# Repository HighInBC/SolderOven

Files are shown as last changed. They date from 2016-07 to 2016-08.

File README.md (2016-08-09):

# SolderOven
A control board to turn a toaster oven and a relay into a solder oven

While this is a public project I am not planning on documenting it until it is somewhat ready.

Consider this to be at the pre-alpha development stage. Things **DO NOT WORK** yet.

##Purpose

The purpose of this board is to act as a solder oven control board.
In addition to providing a user interface it will use a relay to control a toaster oven to provide the functionality of a solder oven.

##Features

Not all of these features are functional yet.

###Microcontroller

An ATMEGA328P-AU sits at the heart of the device controlling all of the other components.

###I2C display

Using an I2C port for an external display will allow a wide variety of choices that can be implemented in firmware

###Rotary encoder

A rotary encoder with a push button will be the primary source of user interaction.

###RGB LED

A ws2812b LED will be able to switch to any color or brightness to act as an indicator.

###Buzzer

A small piezo buzzer is used to make audio signals to the user

###Reset button

To reset the unit

###Serial port

The serial port can be used to reprogram the device.
It features an auto reset circuit on the DTR line to mimic the behaviour of an arduino nano but with an external FTDI bpard.

When not being used for programming the port can be used for peripherals such as a wifi bridge or sd card logger.

###Thermocouple sensor

A MAX6675 is used to read and digitize the signal from a type-k thermocouple. Two female 4mm banana plug sockets are on the board for easy connection. This is used to monitor the temperature of the oven.

###External temperature sensor

A port to attach one or more DS18B20 temperature sensors is available. This is used to monitor the temperature of the relay and its housing, further sensors can be added as it is a 1-wire protocol. Has a built in 4.7K pull-up resistor on the data pin for the 1-wire interface.

###Relay output

A port to attach the logic side of a relay to. It is expected that the relay takes a 5V logic level signal and does its own current limiting under 40mA. If your relay needs more than that then you need to add a suitable transistor.

##Associated datasheets

* [ATMEGA382P-AU](http://www.atmel.com/images/Atmel-8271-8-bit-AVR-Microcontroller-ATmega48A-48PA-88A-88PA-168A-168PA-328-328P_datasheet_Complete.pdf)
* [WS2812B](https://cdn-shop.adafruit.com/datasheets/WS2812B.pdf)
* [MAX6675](https://datasheets.maximintegrated.com/en/ds/MAX6675.pdf)
* [DS18B20](https://datasheets.maximintegrated.com/en/ds/DS18B20.pdf)
* [S8050](http://www.gangyi.com.cn/UploadFiles/2007828165749876.pdf)

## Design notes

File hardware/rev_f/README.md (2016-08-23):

Warning, this board revision has faults. Do not order.

Ordered from OSHPark for testing on 2016-08-05

Received and assembled August 8th, 2016. Results:

The following hardware features work correctly:

- ATMEGA328P-AU MCU
- Auto-program over serial port arduino nano style using external FTDI board
- WS2812B LED
- Buzzer
- Thermocouple reading
- Rotary encoder/button
- Reset button
- I2C display
- Relay ouput
- Power input

Errors on board:

- Mounting holes are too crowded and too close to the edges. Have to expand board size
- The DS18B20 is attached to ADC6, this port is only for analog reading and cannot control the port. Next revision has this moved to PD5

Added a bodge wire from PD5 to the DS18B20 data line. Works correctly.

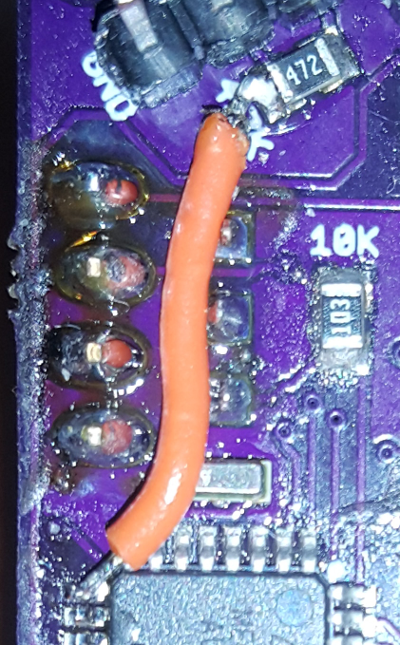
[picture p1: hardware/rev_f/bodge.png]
Bodge


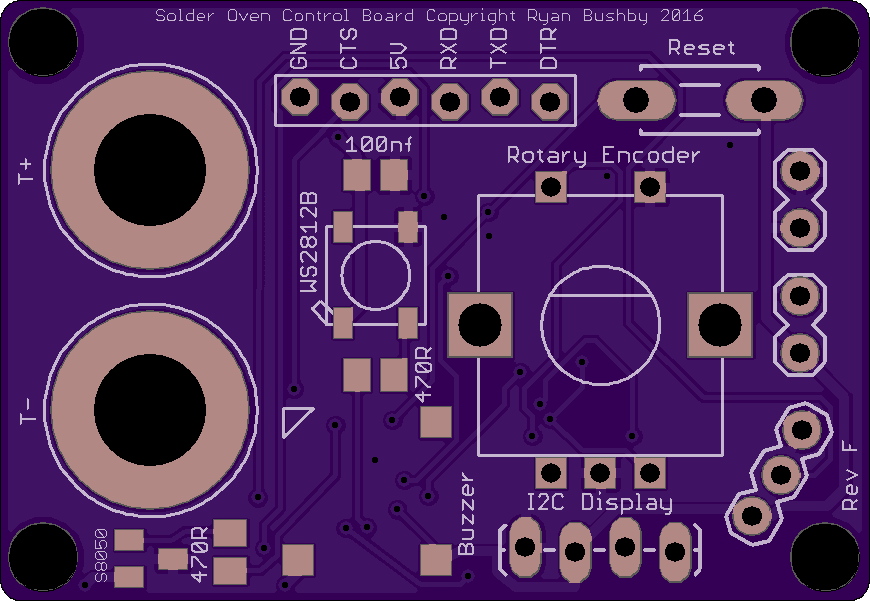
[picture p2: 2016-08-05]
hardware/rev_f/rev_f_front.png

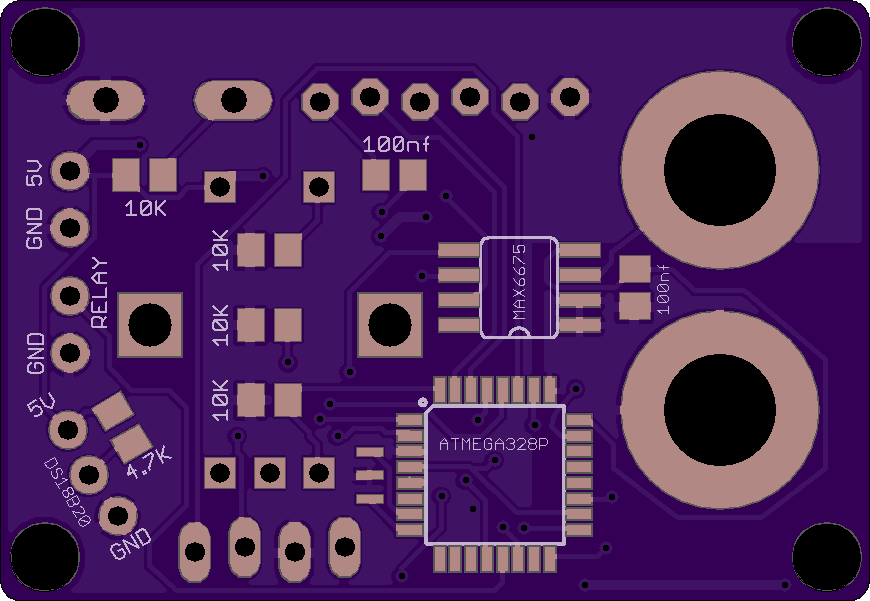
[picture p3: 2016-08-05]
hardware/rev_f/rev_f_back.png

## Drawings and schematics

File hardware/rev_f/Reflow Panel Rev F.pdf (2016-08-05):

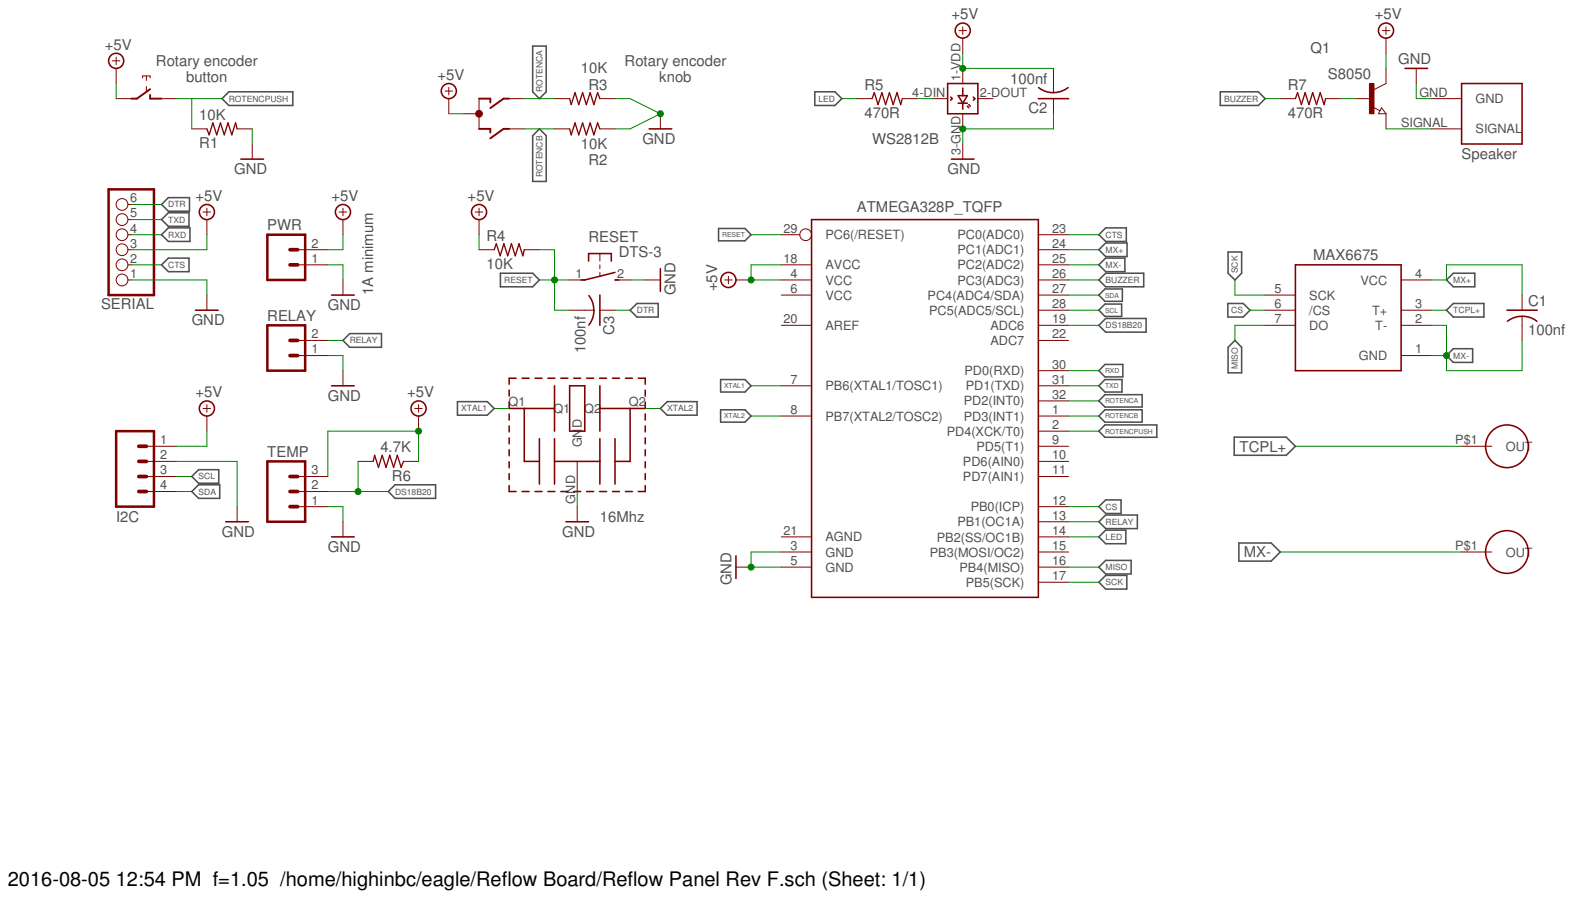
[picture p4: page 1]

2016-08-05 12:54 PM f=1.05 /home/highinbc/eagle/Reflow Board/Reflow Panel Rev F.sch (Sheet: 1/1)

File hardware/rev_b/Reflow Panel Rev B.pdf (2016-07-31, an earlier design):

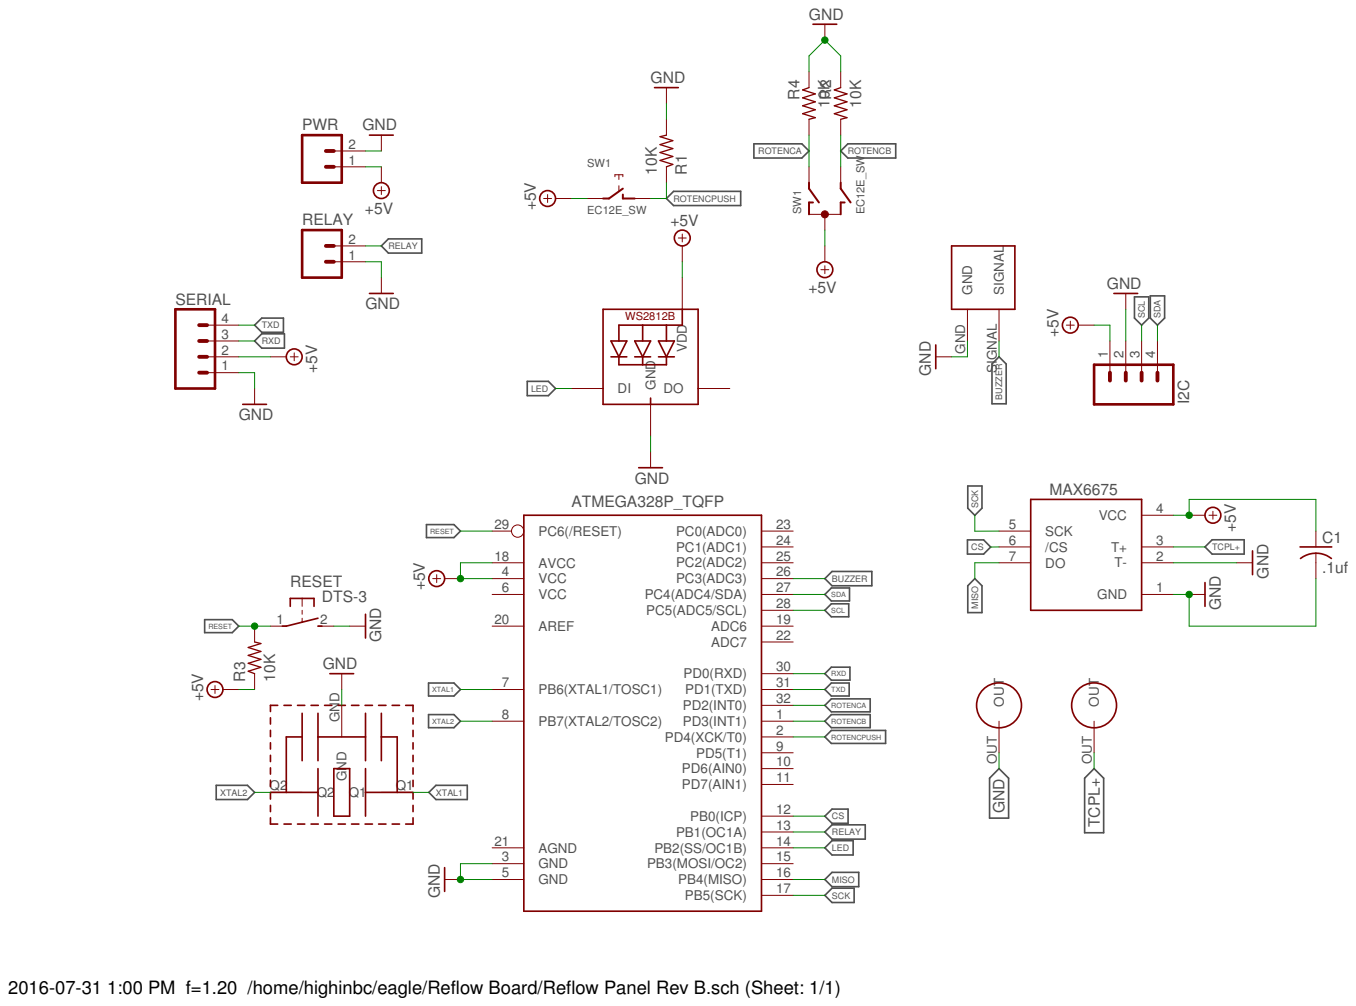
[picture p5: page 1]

OUT OUT

2016-07-31 1:00 PM f=1.20 /home/highinbc/eagle/Reflow Board/Reflow Panel Rev B.sch (Sheet: 1/1)

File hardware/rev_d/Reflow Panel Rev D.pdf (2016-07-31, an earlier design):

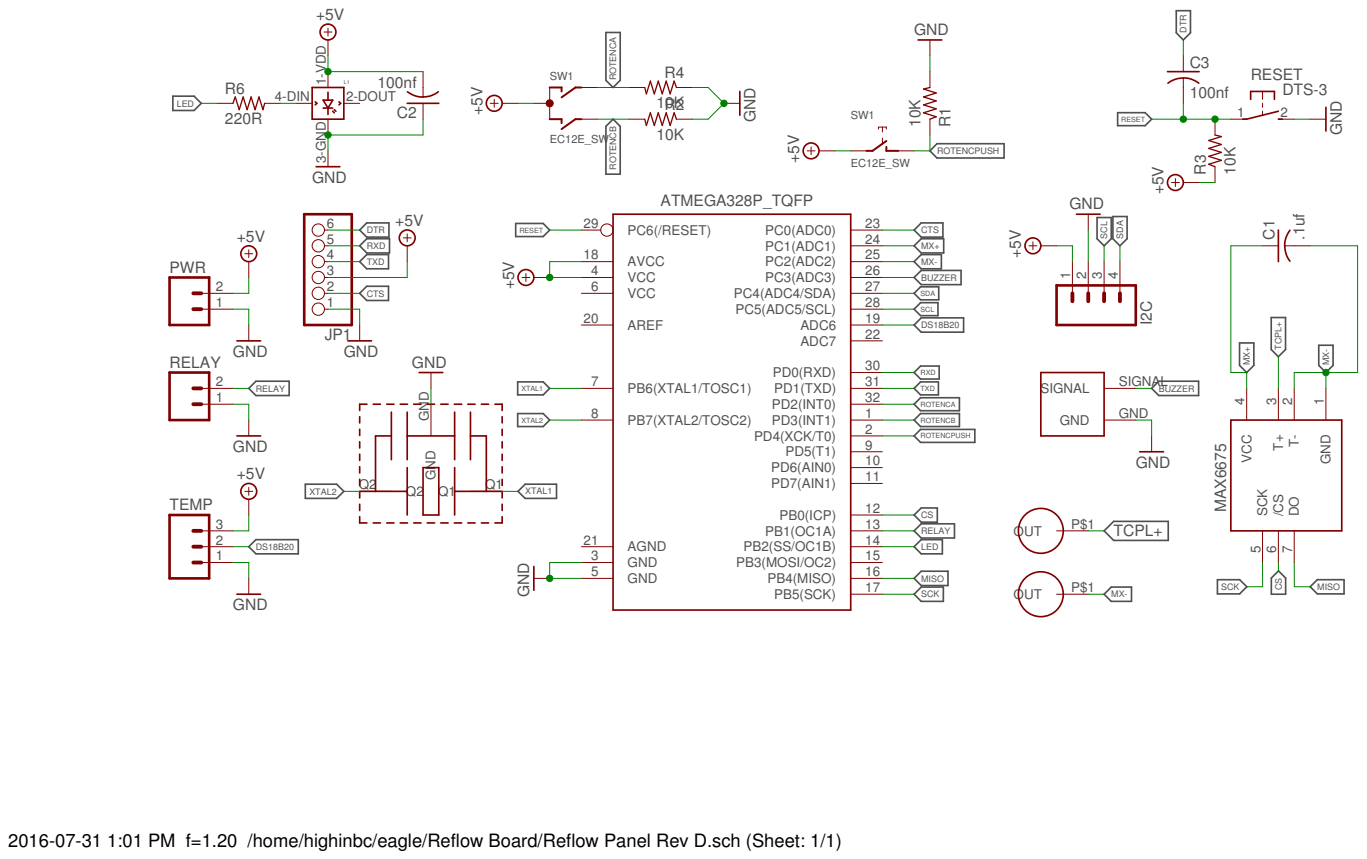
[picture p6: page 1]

2016-07-31 1:01 PM f=1.20 /home/highinbc/eagle/Reflow Board/Reflow Panel Rev D.sch (Sheet: 1/1)

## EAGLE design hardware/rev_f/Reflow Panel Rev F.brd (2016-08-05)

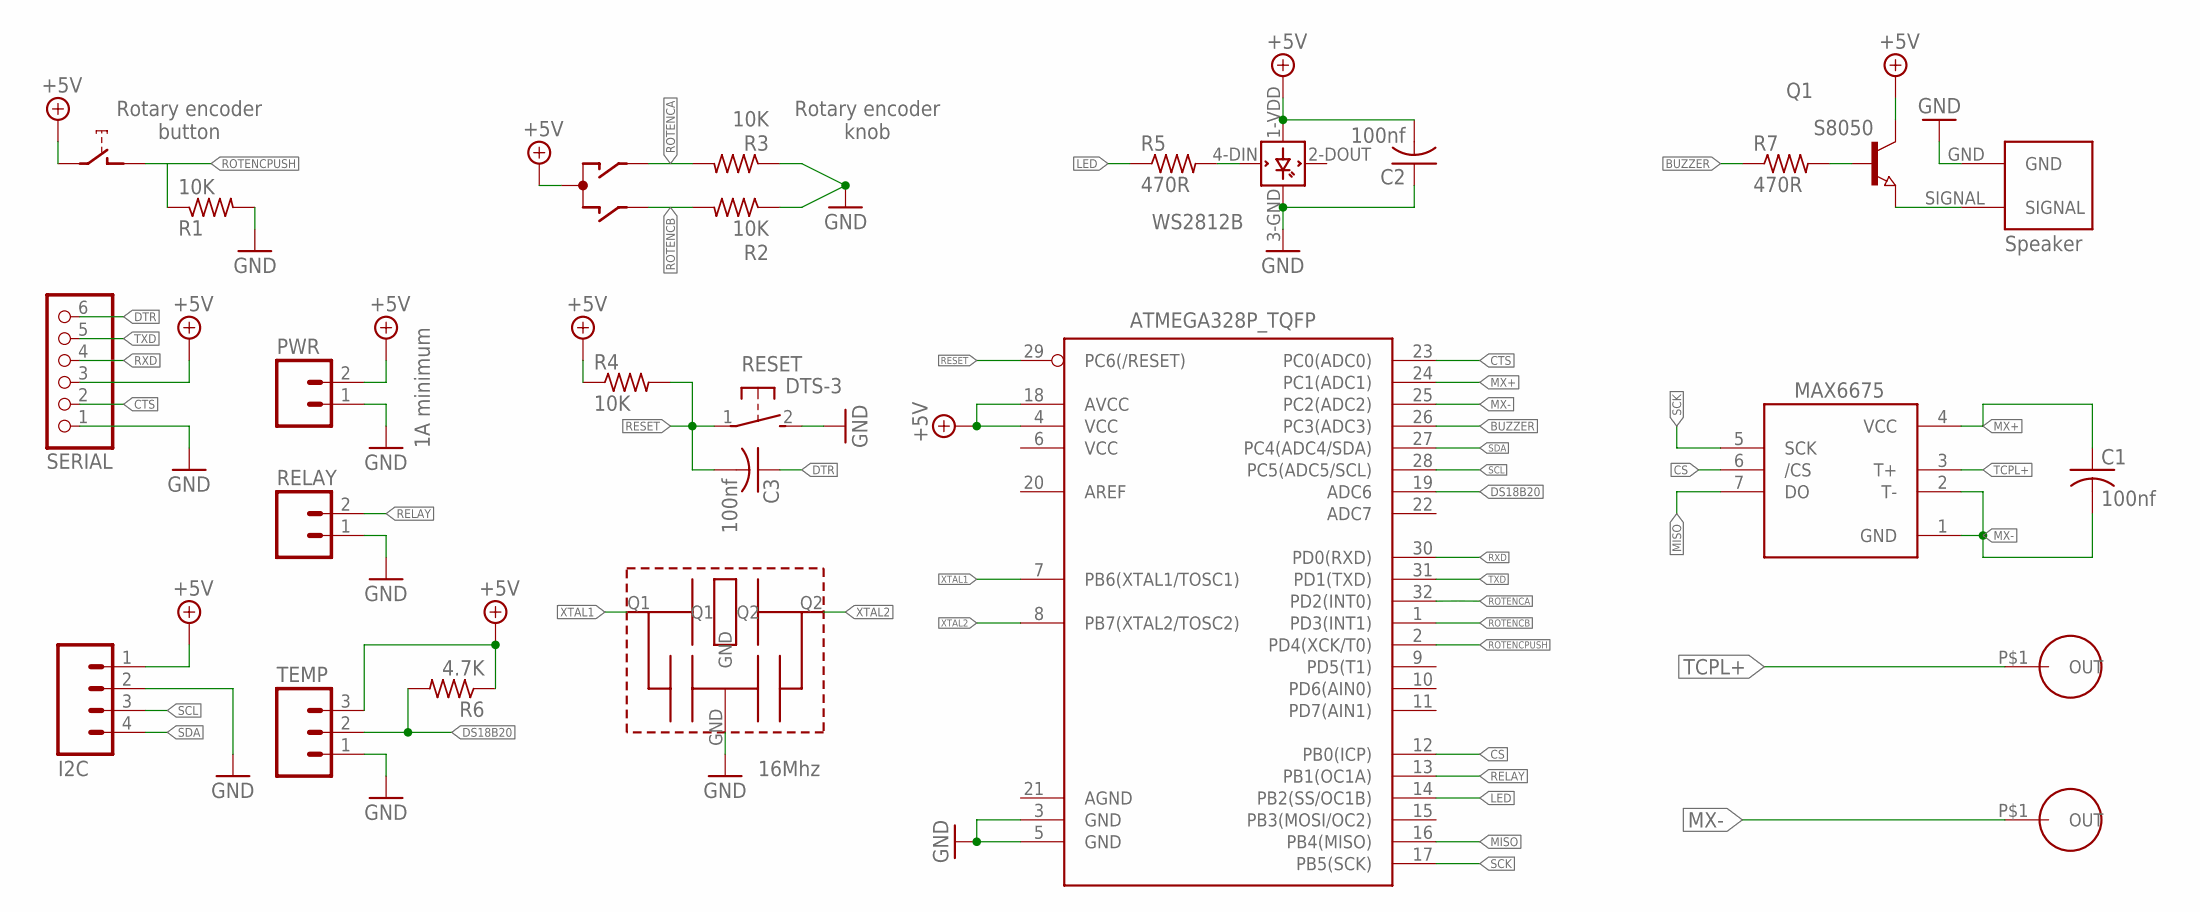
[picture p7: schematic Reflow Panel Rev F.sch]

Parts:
C1, C2, C3: 100nf; C0805
I2C: M04LOCK_LONGPADS; 1X04_LOCK_LONGPADS
IC2: MAX6675; SO08
L1: WS2812B_; WS2812B
PWR: M02LOCK; 1X02_LOCK
Q1: NPN-TRANSISTOR_SOT23; SOT23
R1, R2, R3, R4: 10K; M0805
R5, R7: 470R; M0805
R6: 4.7K; M0805
RELAY: M02LOCK; 1X02_LOCK
RESET: DTS-3
SERIAL: PINHD-1X6LOCK; 1X06-BIGLOCK
SW1: EC12E_SW; ALPS_EC12E_SW
TEMP: M03LOCK; 1X03_LOCK
U1: ATMEGA328P_TQFP; TQFP32-08
U$1: 8.5MMSQUAREBUZZER
U$2: CSTCE16M0V53-R0; CSTCE_V13C
U$3, U$4: BANANAFEMAIL-10.8-5.7; BANANAFEMALE-10.8-5.7

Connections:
+5V: C2.2, I2C.1, L1.1-VDD (VDD), PWR.2, Q1.3 (C), R4.1, R6.1, SERIAL.3, SW1.C, SW1.E (2), TEMP.3, U1.4 (VCC), U1.18 (AVCC)
BUZZER: R7.1, U1.26 (PC3(ADC3))
CS: IC2.6 (/CS), U1.12 (PB0(ICP))
CTS: SERIAL.2, U1.23 (PC0(ADC0))
DS18B20: R6.2, TEMP.2, U1.19 (ADC6)
DTR: C3.1, SERIAL.6
GND: C2.1, I2C.2, L1.3-GND (GND), PWR.1, R1.2, R2.1, R3.1, RELAY.1, RESET.2, SERIAL.1, TEMP.1, U1.3 (GND), U1.5 (GND), U$1.GND, U$2.GND
LED: R5.1, U1.14 (PB2(SS/OC1B))
MISO: IC2.7 (DO), U1.16 (PB4(MISO))
MX+: C1.1, IC2.4 (VCC), U1.24 (PC1(ADC1))
MX-: C1.2, IC2.1 (GND), IC2.2 (T-), U1.25 (PC2(ADC2)), U$3.P$1
unnamed: L1.4-DIN (DIN), R5.2
unnamed: Q1.2 (E), U$1.SIGNAL
unnamed: Q1.1 (B), R7.2
RELAY: RELAY.2, U1.13 (PB1(OC1A))
RESET: C3.2, R4.2, RESET.1, U1.29 (PC6(/RESET))
ROTENCA: R3.2, SW1.A, U1.32 (PD2(INT0))
ROTENCB: R2.2, SW1.B, U1.1 (PD3(INT1))
ROTENCPUSH: R1.1, SW1.D (1), U1.2 (PD4(XCK/T0))
RXD: SERIAL.4, U1.30 (PD0(RXD))
SCK: IC2.5 (SCK), U1.17 (PB5(SCK))
SCL: I2C.3, U1.28 (PC5(ADC5/SCL))
SDA: I2C.4, U1.27 (PC4(ADC4/SDA))
TCPL+: IC2.3 (T+), U$4.P$1
TXD: SERIAL.5, U1.31 (PD1(TXD))
XTAL1: U1.7 (PB6(XTAL1/TOSC1)), U$2.Q1
XTAL2: U1.8 (PB7(XTAL2/TOSC2)), U$2.Q2

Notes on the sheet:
Speaker
S8050
WS2812B
Rotary encoder button
Rotary encoder knob
16Mhz
1A minimum

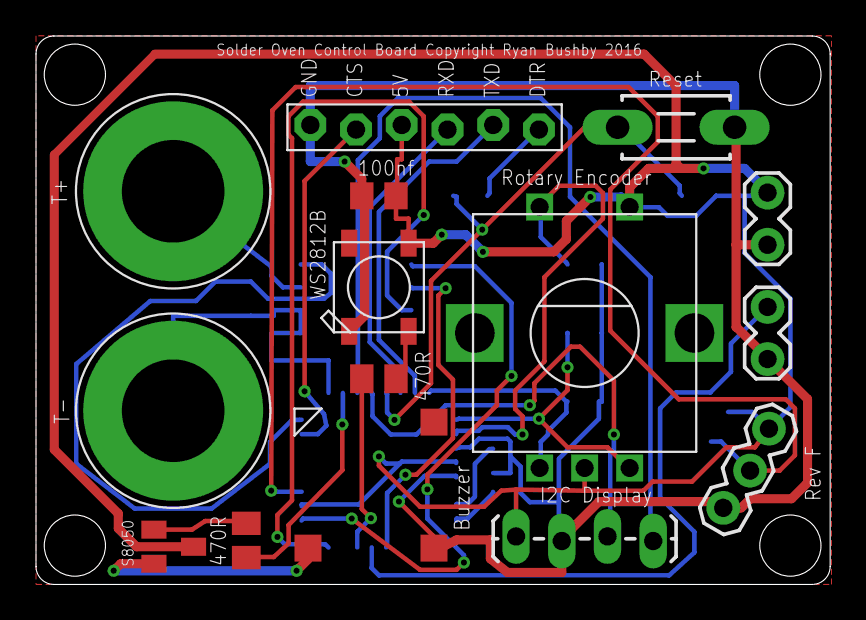
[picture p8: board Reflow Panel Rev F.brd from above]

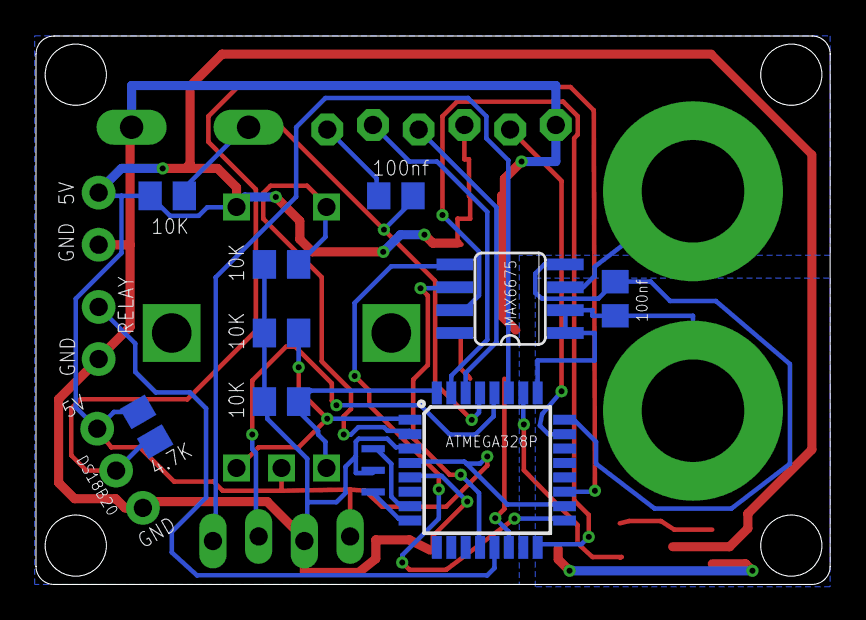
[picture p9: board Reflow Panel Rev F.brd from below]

Board: 2 copper layers, 44.1 x 30.5 mm, 25 parts (10 on the bottom side), 27 nets.

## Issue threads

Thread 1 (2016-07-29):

WS2812b LED does not work

HighInBC, 2016-07-29:
As of hardware Rev B

The LED gets power, the gpio pin is correctly connected, but it does not light.

Getting oscilloscope tomorrow to look at signal. Adding signal resistor and decoupling cap for subsequent revisions.

HighInBC, 2016-07-29:
Oscilloscope showed severe ringing on the wave forms of the signal. A 220 ohm resistor in series eliminated it. A 100nf decoupling capacitor was added. The LED now works.

Closed 2016-07-29.

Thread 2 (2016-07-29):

Buzzer is over currenting GPIO pin on atmega328

HighInBC, 2016-07-29:
As of hardware rev B

The buzzer can draw up to 80mA which is double what the gpio pin is meant to do. Needs to be driven with a transistor.

HighInBC, 2016-07-29:
Added S8050 transistor to drive buzzer.

Closed 2016-07-29.

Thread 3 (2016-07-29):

Add external temperature sensor

HighInBC, 2016-07-29:
Add external temperature sensor for monitoring relay temperature

HighInBC, 2016-07-29:
Prototype board is missing 4.7k pull up resistor.

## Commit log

2016-07-29 Adding current state of design
    [Reflow Panel Rev F.brd, Reflow Panel Rev F.sch]
2016-07-29 remove irrelevant info, add specific current limit
2016-07-29 about relay control pin limits
2016-07-31 organize folders
    [Reflow Panel Rev F.brd, Reflow Panel Rev F.sch]
2016-07-31 prior boards ordered
    [Reflow Panel Rev B.brd, Reflow Panel Rev B.sch, Reflow Panel Rev D.brd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]
2016-08-05 silkscreen mod, order update
    [Reflow Panel Rev F.brd, Reflow Panel Rev F.sch]

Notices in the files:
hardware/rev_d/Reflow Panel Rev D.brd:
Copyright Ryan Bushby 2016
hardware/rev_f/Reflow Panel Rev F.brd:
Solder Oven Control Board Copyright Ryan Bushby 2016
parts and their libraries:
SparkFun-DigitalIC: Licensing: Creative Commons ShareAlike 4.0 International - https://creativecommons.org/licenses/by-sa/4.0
